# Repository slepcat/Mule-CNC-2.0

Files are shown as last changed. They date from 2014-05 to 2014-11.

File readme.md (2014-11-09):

# Mule CNC 2.0 Read me

Mule CNC 2.0は3Dプリント部品を使って構築したCNCミルです。

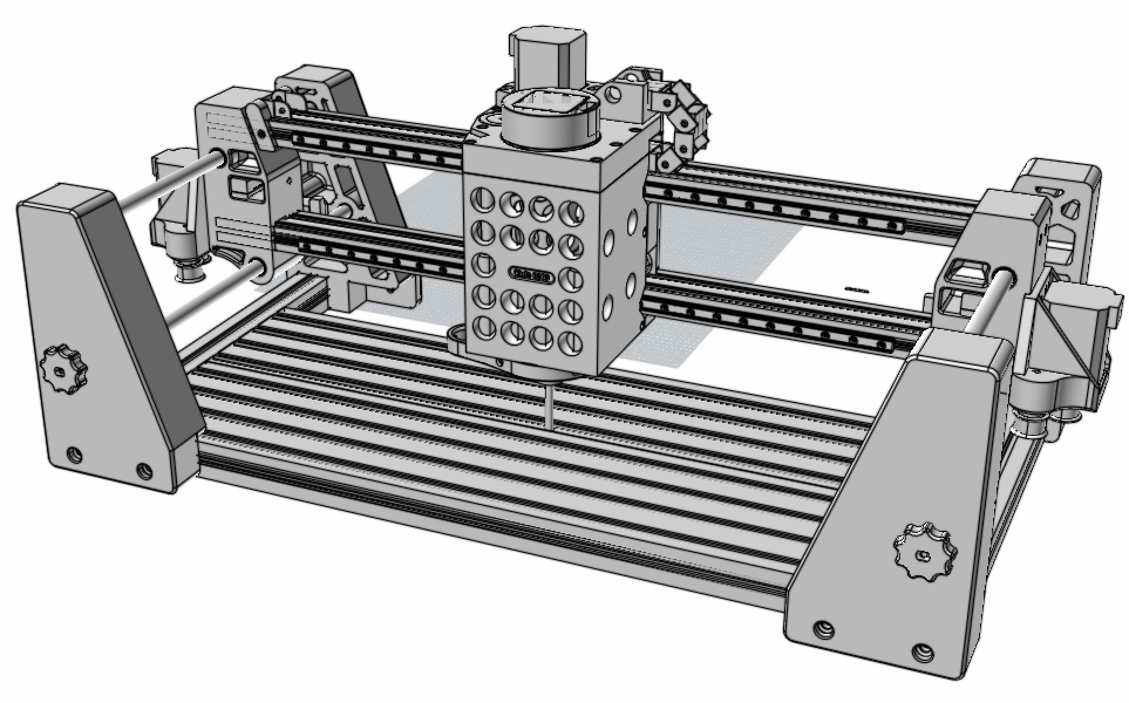
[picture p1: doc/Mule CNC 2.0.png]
Mule CNC 2.0 CAD


###主な特徴
* 3Dプリント部品。主軸を含む主要な部品をPLAで3Dプリントしています。3Dプリンタを使って構築が可能ですが、Replicator2のような造形サイズの大きいプリンタが必要です
* モーションコントローラとしてTinyGを使用しています
* 主軸モータとしてRC用のブラシレスDCモータを使用しています。	主軸回転数をTinyGから制御できます
* 剛性。アルミや真鍮といったソフトメタルを切削できます

###その他
* PLAは熱に弱いため、ステッパモータに流す電流量は注意する必要があります。発熱は3Dプリント部品を痛めるおそれがあります
* リミットスイッチはデザインに組み込まれていますが、作者はまだ実装していません
* 資料類は整理中です

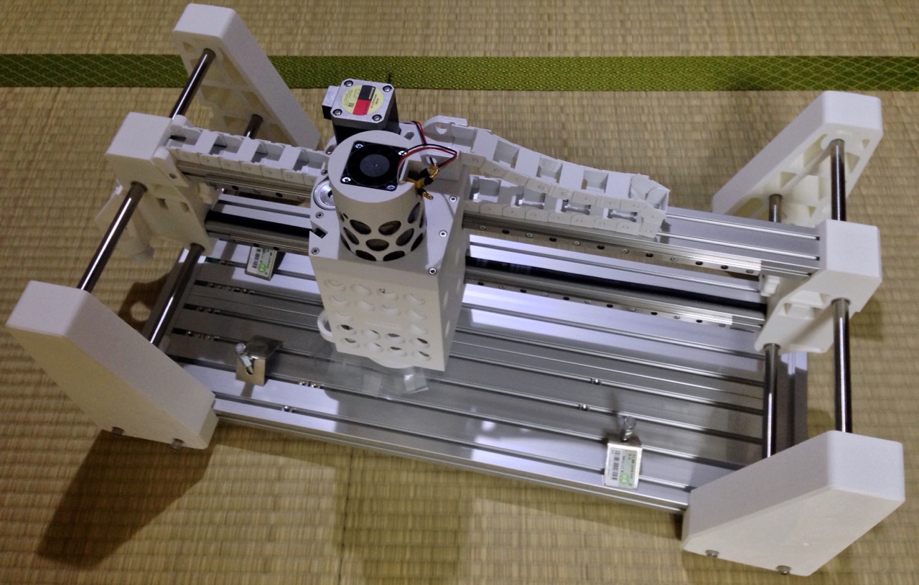
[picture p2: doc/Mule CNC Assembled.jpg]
Mule CNC under assemble


##English Ver.

Mule CNC 2.0 is CNC milling machine made with 3D Printed Parts.

###Features
* Use of 3D printed parts. Significant parts including spindle are 3D printable with PLA.
    (It require large build volume. ex, Replicator2)
* Motion controller is TinyG.
* RC's Brushless DC Motor for spindle. RPM can be controlled with TinyG.
* Rigidness. it can cut soft metals (Aluminum & Brass)
* Reduced noise.

###Note
* Mule CNC use commercial parts available in Japan. Some of them might unable to purchase outside of Japan.
* PLA is weak to heat. You should keep the current for steppers moderate to avoid heat damage.
* Limit switch has not been implemented yet.
* Documents are under construction.

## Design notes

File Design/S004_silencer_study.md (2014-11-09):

# Stepper motor silencer

マウントに防振材を挟む方式
[Motor housing with dumper](http://www.thingiverse.com/thing:25205)

モーター本体を金属たわしとアルミホイルでくるむ方式もあった筈だが論文が見つからない。
どこに行ったのか…

# Spindle silencer & EM noise sheild

アルミホイルで覆うのが手っ取り早い？

## 12th June 2014 silencer test result

* SK3 Brushless DC apx. 5000 rpm
* Use "dB-Meter Free" iPhone app. 10 cm distance from spindle.
* Results
	* 1.0 Design: avg 80dB / peak 90dB
	* Cardboard Box: avg 77dB / peak 87dB
	* Aluminum foil: avg 78dB / peak 88dB
	* Foil & steel wool: avg 76dB / peak 86dB

アルミホイルとスチールウールでも思ったほど落ちない。あとはモータをゴムでマウントする、アルミフォイルではなく厚いアルミ板を使用することを検討。

## 14th June 2014 dumper mount test result

* SK3 Brushless DC apx. 5000 rpm
* Use "dB-Meter Free" iPhone app. 10 cm distance from spindle.
* Results
	* Dumper (Rubber Mount): avg 72dB / peak 80dB
	* Dumper & foil: avg 71dB / peak 79dB

ダンパーで劇的に改善。3mm厚のゴムをThingiverseを参考に挟み込む。
Ref: [Silencer Kit for NEMA 17 Steppers](http://www.thingiverse.com/thing:25205)

Ref. Makerbot Replicator 2: avg 63dB / peak 73dB

## 16th June 2013 lead tape test result

* SK3 Brushless DC apx. 5000 rpm
* Use "dB-Meter Free" iPhone app. 10 cm distance from spindle.
* dc housing with silencer case
* Results
	* Dumper, on the towel: avg 69dB / peak 76dB
	* Dumper: avg 72dB / peak 80dB
	* Dumper, lead tape, on the sponge avg 69dB / peak 76dB

鉛テープに効果なし。ハウジングとスピンドルブロックにダンパーを挟み込むことに効果がありそう
だと判明。

音響インピーダンスに付いてアドバイスをもらう。空気／スポンジ／鉛テープの層にすれば効果があ
るかも。

## 17th June 2014 sponge test result

* SK3 Brushless DC apx. 5000 rpm
* Use "dB-Meter Free" iPhone app. 10 cm distance from spindle.
* dc housing with silencer case
* Results
	* Dumper, lead/sponge on sponge: avg 65dB / peak 72dB

効果があるようですが放熱が心配。

ノイズ対策レシピ
Anti Noise recipes from CNC Cookbook
http://www.cnccookbook.com/CCCNCNoise.html

## 14th September 2014 new motor

* SNTM 28-26 1100KV Brushless DC apx. 5000 rpm?
* Use "dB-Meter Free" iPhone app. 10 cm distance from spindle.
* dc housing with silencer case
* Results
	* Dumper: avg 60dB / peak 67dB

モータ交換した事で劇的に改善。しばらくSK3で運用していたがこちらに交換する事を決断。ハウジングのデザインも多少見直す予定。
なお、SK3はシャフトに取り付けていた軸ががたついていたのでこれも騒音の一因だったかも。いずれにしても高回転のモータは騒音面でデメリットが大きいかも。SK3しか使っていないので分かりませんが。

## 9th November 2014 Round up

本体に組み込んだところ、ハウジングの振動でキャリッジと接触して騒音が大きくなることが判明。
スピンドル周りを一回り小さくなるように造形し直し、キャリッジとクリアランスを確保。
スピンドルを再作成する際に排気口を追加、スピンドルモータの冷却風がスピンドル下面から流れ出るようにデザインを修正。これでハウジングに排気口をつける必要がなくなり騒音を密閉できるように。また切削時のエアブローとしても多少期待できるかも？

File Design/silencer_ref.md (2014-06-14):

# Stepper motor silencer

マウントに防振材を挟む方式
[Motor housing with dumper](http://www.thingiverse.com/thing:25205)

モーター本体を金属たわしとアルミホイルでくるむ方式もあった筈だが論文が見つからない。
どこに行ったのか…
I've seen the paper describe stepper silencer with aluminium foil and steel wool, but I cann't find it.

# Spindle silencer & EM noise sheild

アルミホイルで覆うのが手っ取り早い？
Aluminum sheet may be good considering EM noise of Spindle...

## 12th June 2014 silencer test result

* SK3 Brushless DC apx. 5000rpm
* Use "dB-Meter Free" iPhone app. 10cm distance from spindle.
* Resutls
	* 1.0 Design: avg 80dB / peak 90db
	* Cardboard Box: avg 77dB / peak 87dB
	* Aluminum foil: avg 78dB / peak 88dB
	* Foil & steel wool: avg 76dB / peak 86dB

アルミホイルとスチールウールでも思ったほど落ちない。あとはモータをゴムでマウントする、アルミフォイルではなく厚いアルミ板を使用することを検討。
Foil & steel wool failed to reach the expectation. Motor housing with dumper and thicker aluminum sheet may be effective.

## 14th June 2014 dumper mount test result

* SK3 Brushless DC apx. 5000rpm
* Use "dB-Meter Free" iPhone app. 10cm distance from spindle.
* Resutls
	* Dumper (Rubber Mount): avg 72dB / peak 80dB
	* Sumper & foil: avg 71dB / peak 79dB

Use dumper mount of 3mm thickness rubber sheets. Big improvement!
ダンパーで劇的に改善。3mm厚のゴムをThingiverseを参考に挟み込む。
Ref: [Silencer Kit for NEMA 17 Steppers](http://www.thingiverse.com/thing:25205)

ノイズ対策レシピ
Anti Noise recipes from CNC Cookbook
http://www.cnccookbook.com/CCCNCNoise.html

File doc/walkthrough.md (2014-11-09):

#フォルダ構成の説明

* CAD/ : MoI 2.5で作成したCADデータ。市販部品のデータが組み込まれていますが、こちらは当然元々のメーカのものですのでご注意ください
* Design/ : 静音化のときの試行錯誤のメモとか、強度計算もどきのメモなんかが残っています
* doc/ : ライセンスとこのファイル。BoMもここに入れる予定です
* readme.md
* STL & NC : CADデータから出力したstlデータです。3Dプリント用にサポートなどがついた状態になっています
* Test : 製作時に行った各種テストのデータです
	* Arduino_rpm_sensor : Arduinoを使った主軸回転数計。要改良
	* Arduino_tmp_sensor : Arduinoを使った温度計

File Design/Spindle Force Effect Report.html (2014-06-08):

(https://forceeffect.autodesk.com)

For correct interpretation of this picture you need to use IE9, Chrome, Safari or Firefox

## Inputs:

### Elements

Element | Length | Weight
A-B | 49.000 mm
B-C | 91.000 mm
B-D | 42.000 mm
A-E | 42.000 mm

### Forces

Force | Direction | Size | Angle
F1 | | 50.000 N | 360.0°
F2 | | 10.000 N | 90.2°

## Results:

Overconstrained System: No equations available.

### Reaction Forces

Force | Direction | Size | Angle
RD | | 138.563 N | 206.5°
RE | | 90.375 N | 35.0°

### Reaction Moments

Moment | Direction | Size
MD | | 546.977 Nmm
ME | | 1043.665 Nmm

## Element A-B

For correct interpretation of this picture you need to use IE9, Chrome, Safari or Firefox

Results (No equations available)
Mr3s1i11 = −1132.734 Nmm Mr3s1i2 = 1132.734 Nmm Mr3s2i5 = −4546.652 Nmm Mr3s2i8 = 2049.606 Nmm Mr6s1i2 = 2497.046 Nmm | Rr1s1i11 = −74.048 N Rr1s1i2 = 74.048 N Rr1s2i5 = −49.964 N Rr1s2i8 = 124.012 N Rr2s1i11 = −51.812 N | Rr2s1i2 = 51.812 N Rr2s2i5 = −10.000 N Rr2s2i8 = 61.812 N Rr4s1i2 = −74.048 N Rr5s1i2 = −51.812 N

### Shear Force and Moment Diagram

For correct interpretation of this picture you need to use IE9, Chrome, Safari or Firefox

For correct interpretation of this picture you need to use IE9, Chrome, Safari or Firefox

For correct interpretation of this picture you need to use IE9, Chrome, Safari or Firefox

## Element A-E

For correct interpretation of this picture you need to use IE9, Chrome, Safari or Firefox

Results (No equations available)
Mr3s1i11 = −1132.734 Nmm Mr3s1i2 = 1132.734 Nmm Mr6s1i11 = −1043.665 Nmm | Rr1s1i11 = −74.048 N Rr1s1i2 = 74.048 N Rr2s1i11 = −51.812 N | Rr2s1i2 = 51.812 N Rr4s1i11 = 74.048 N Rr5s1i11 = 51.812 N

### Shear Force and Moment Diagram

For correct interpretation of this picture you need to use IE9, Chrome, Safari or Firefox

For correct interpretation of this picture you need to use IE9, Chrome, Safari or Firefox

## Element B-C

For correct interpretation of this picture you need to use IE9, Chrome, Safari or Firefox

Results (No equations available)
Mr3s2i5 = −4546.652 Nmm Mr3s2i8 = 2049.606 Nmm Mr6s1i2 = 2497.046 Nmm Mr6s2i5 = 0.000 Nmm | Rr1s2i5 = −49.964 N Rr1s2i8 = 124.012 N Rr2s2i5 = −10.000 N Rr2s2i8 = 61.812 N | Rr4s1i2 = −74.048 N Rr4s2i5 = 49.964 N Rr5s1i2 = −51.812 N Rr5s2i5 = 10.000 N

### Shear Force and Moment Diagram

For correct interpretation of this picture you need to use IE9, Chrome, Safari or Firefox

For correct interpretation of this picture you need to use IE9, Chrome, Safari or Firefox

For correct interpretation of this picture you need to use IE9, Chrome, Safari or Firefox

## Element B-D

For correct interpretation of this picture you need to use IE9, Chrome, Safari or Firefox

Results (No equations available)
Mr3s2i5 = −4546.652 Nmm Mr3s2i8 = 2049.606 Nmm Mr6s1i2 = 2497.046 Nmm Mr6s2i8 = 546.977 Nmm | Rr1s2i5 = −49.964 N Rr1s2i8 = 124.012 N Rr2s2i5 = −10.000 N Rr2s2i8 = 61.812 N | Rr4s1i2 = −74.048 N Rr4s2i8 = −124.012 N Rr5s1i2 = −51.812 N Rr5s2i8 = −61.812 N

### Shear Force and Moment Diagram

For correct interpretation of this picture you need to use IE9, Chrome, Safari or Firefox

For correct interpretation of this picture you need to use IE9, Chrome, Safari or Firefox

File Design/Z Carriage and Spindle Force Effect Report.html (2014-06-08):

(https://forceeffect.autodesk.com)

For correct interpretation of this picture you need to use IE9, Chrome, Safari or Firefox

## Inputs:

### Elements

Element | Length | Weight
A-B | 49.000 mm
B-C | 91.000 mm
B-D | 42.000 mm
A-E | 42.000 mm
D-F | 10.000 mm
D-E | 49.000 mm
E-G | 81.000 mm

### Forces

Force | Direction | Size | Angle
F1 | | 50.000 N | 360.0°
F2 | | 10.000 N | 90.2°

## Results:

Overconstrained System: No equations available.

### Reaction Forces

Force | Direction | Size | Angle
RF | | 100.105 N | 214.0°
RG | | 56.623 N | 54.3°

### Reaction Moments

Moment | Direction | Size
MF | | 160.443 Nmm
MG | | 1155.783 Nmm

## Element A-B

For correct interpretation of this picture you need to use IE9, Chrome, Safari or Firefox

Results (No equations available)
Mr3s1i11 = −928.458 Nmm Mr3s1i2 = 928.458 Nmm Mr3s2i5 = −4546.652 Nmm Mr3s2i8 = 2126.766 Nmm Mr6s1i2 = 2419.887 Nmm | Rr1s1i11 = −68.310 N Rr1s1i2 = 68.310 N Rr1s2i5 = −49.964 N Rr1s2i8 = 118.274 N Rr2s1i11 = −41.972 N | Rr2s1i2 = 41.972 N Rr2s2i5 = −10.000 N Rr2s2i8 = 51.972 N Rr4s1i2 = −68.310 N Rr5s1i2 = −41.972 N

### Shear Force and Moment Diagram

For correct interpretation of this picture you need to use IE9, Chrome, Safari or Firefox

For correct interpretation of this picture you need to use IE9, Chrome, Safari or Firefox

For correct interpretation of this picture you need to use IE9, Chrome, Safari or Firefox

## Element A-E

For correct interpretation of this picture you need to use IE9, Chrome, Safari or Firefox

Results (No equations available)
Mr3s11i23 = 1517.740 Nmm Mr3s1i11 = −928.458 Nmm Mr3s1i2 = 928.458 Nmm Mr6s1i11 = −834.618 Nmm Mr6s8i11 = −683.122 Nmm | Rr1s11i23 = −33.006 N Rr1s1i11 = −68.310 N Rr1s1i2 = 68.310 N Rr2s11i23 = −46.008 N Rr2s1i11 = −41.972 N | Rr2s1i2 = 41.972 N Rr4s1i11 = 68.310 N Rr4s8i11 = −35.304 N Rr5s1i11 = 41.972 N Rr5s8i11 = 4.036 N

### Shear Force and Moment Diagram

For correct interpretation of this picture you need to use IE9, Chrome, Safari or Firefox

For correct interpretation of this picture you need to use IE9, Chrome, Safari or Firefox

## Element B-C

For correct interpretation of this picture you need to use IE9, Chrome, Safari or Firefox

Results (No equations available)
Mr3s2i5 = −4546.652 Nmm Mr3s2i8 = 2126.766 Nmm Mr6s1i2 = 2419.887 Nmm Mr6s2i5 = 0.000 Nmm | Rr1s2i5 = −49.964 N Rr1s2i8 = 118.274 N Rr2s2i5 = −10.000 N Rr2s2i8 = 51.972 N | Rr4s1i2 = −68.310 N Rr4s2i5 = 49.964 N Rr5s1i2 = −41.972 N Rr5s2i5 = 10.000 N

### Shear Force and Moment Diagram

For correct interpretation of this picture you need to use IE9, Chrome, Safari or Firefox

For correct interpretation of this picture you need to use IE9, Chrome, Safari or Firefox

For correct interpretation of this picture you need to use IE9, Chrome, Safari or Firefox

## Element B-D

For correct interpretation of this picture you need to use IE9, Chrome, Safari or Firefox

Results (No equations available)
Mr3s2i5 = −4546.652 Nmm Mr3s2i8 = 2126.766 Nmm Mr3s8i11 = −1046.645 Nmm Mr3s8i19 = 990.149 Nmm Mr6s1i2 = 2419.887 Nmm Mr6s2i8 = 56.496 Nmm | Rr1s2i5 = −49.964 N Rr1s2i8 = 118.274 N Rr1s8i11 = 35.304 N Rr1s8i19 = 82.971 N Rr2s2i5 = −10.000 N Rr2s2i8 = 51.972 N | Rr2s8i11 = −4.036 N Rr2s8i19 = 56.007 N Rr4s1i2 = −68.310 N Rr4s2i8 = −118.274 N Rr5s1i2 = −41.972 N Rr5s2i8 = −51.972 N

### Shear Force and Moment Diagram

For correct interpretation of this picture you need to use IE9, Chrome, Safari or Firefox

For correct interpretation of this picture you need to use IE9, Chrome, Safari or Firefox

## Element D-E

For correct interpretation of this picture you need to use IE9, Chrome, Safari or Firefox

Results (No equations available)
Mr3s11i23 = 1517.740 Nmm Mr3s8i11 = −1046.645 Nmm Mr3s8i19 = 990.149 Nmm Mr6s1i11 = −834.618 Nmm Mr6s2i8 = 56.496 Nmm Mr6s8i11 = −683.122 Nmm | Rr1s11i23 = −33.006 N Rr1s8i11 = 35.304 N Rr1s8i19 = 82.971 N Rr2s11i23 = −46.008 N Rr2s8i11 = −4.036 N Rr2s8i19 = 56.007 N | Rr4s1i11 = 68.310 N Rr4s2i8 = −118.274 N Rr4s8i11 = −35.304 N Rr5s1i11 = 41.972 N Rr5s2i8 = −51.972 N Rr5s8i11 = 4.036 N

### Shear Force and Moment Diagram

For correct interpretation of this picture you need to use IE9, Chrome, Safari or Firefox

For correct interpretation of this picture you need to use IE9, Chrome, Safari or Firefox

For correct interpretation of this picture you need to use IE9, Chrome, Safari or Firefox

## Element D-F

For correct interpretation of this picture you need to use IE9, Chrome, Safari or Firefox

Results (No equations available)
Mr3s8i11 = −1046.645 Nmm Mr3s8i19 = 990.149 Nmm Mr6s2i8 = 56.496 Nmm Mr6s8i19 = −160.443 Nmm | Rr1s8i11 = 35.304 N Rr1s8i19 = 82.971 N Rr2s8i11 = −4.036 N Rr2s8i19 = 56.007 N | Rr4s2i8 = −118.274 N Rr4s8i19 = −82.971 N Rr5s2i8 = −51.972 N Rr5s8i19 = −56.007 N

### Shear Force and Moment Diagram

For correct interpretation of this picture you need to use IE9, Chrome, Safari or Firefox

For correct interpretation of this picture you need to use IE9, Chrome, Safari or Firefox

## Element E-G

For correct interpretation of this picture you need to use IE9, Chrome, Safari or Firefox

Results (No equations available)
Mr3s11i23 = 1517.740 Nmm Mr6s11i23 = 1155.783 Nmm Mr6s1i11 = −834.618 Nmm Mr6s8i11 = −683.122 Nmm | Rr1s11i23 = −33.006 N Rr2s11i23 = −46.008 N Rr4s11i23 = 33.006 N Rr4s1i11 = 68.310 N | Rr4s8i11 = −35.304 N Rr5s11i23 = 46.008 N Rr5s1i11 = 41.972 N Rr5s8i11 = 4.036 N

### Shear Force and Moment Diagram

For correct interpretation of this picture you need to use IE9, Chrome, Safari or Firefox

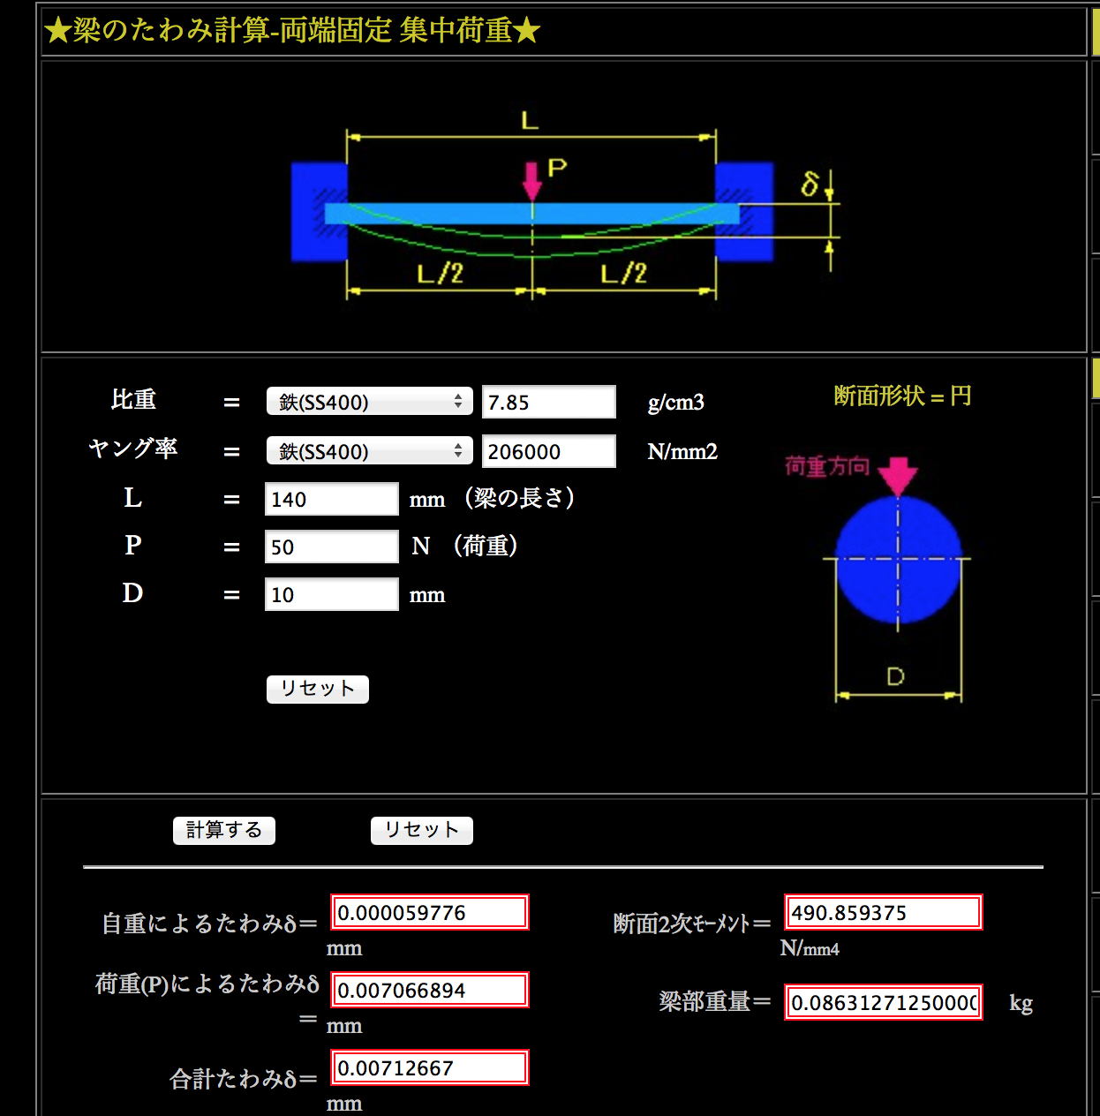
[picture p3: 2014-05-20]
Design/Z Axis Shaft Strength Calc.png

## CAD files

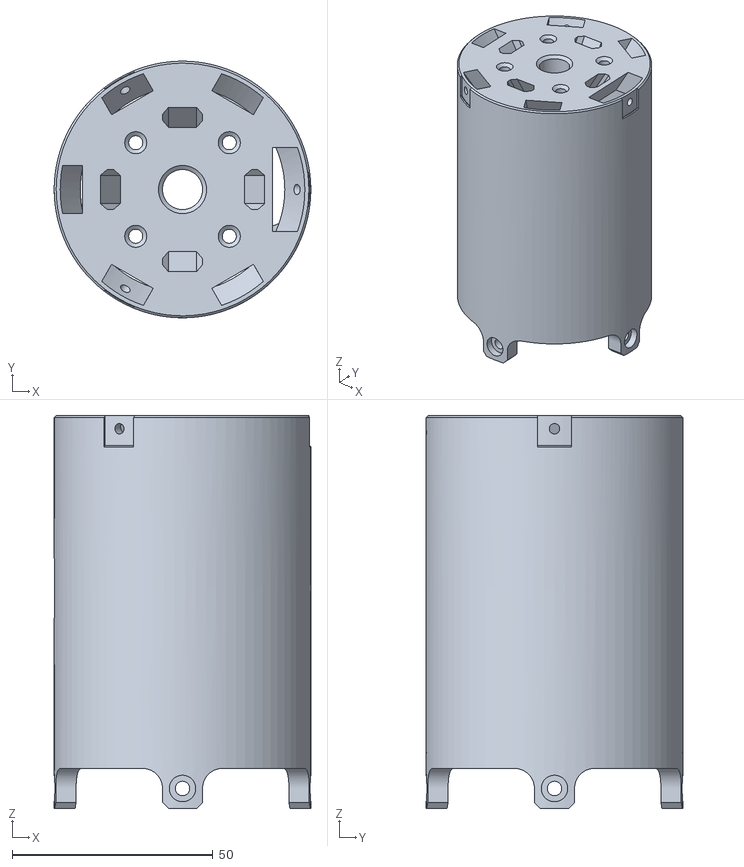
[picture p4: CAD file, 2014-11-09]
STL&NC/S001 dc housing 2.2.stl
64.0 x 64.0 x 98.0

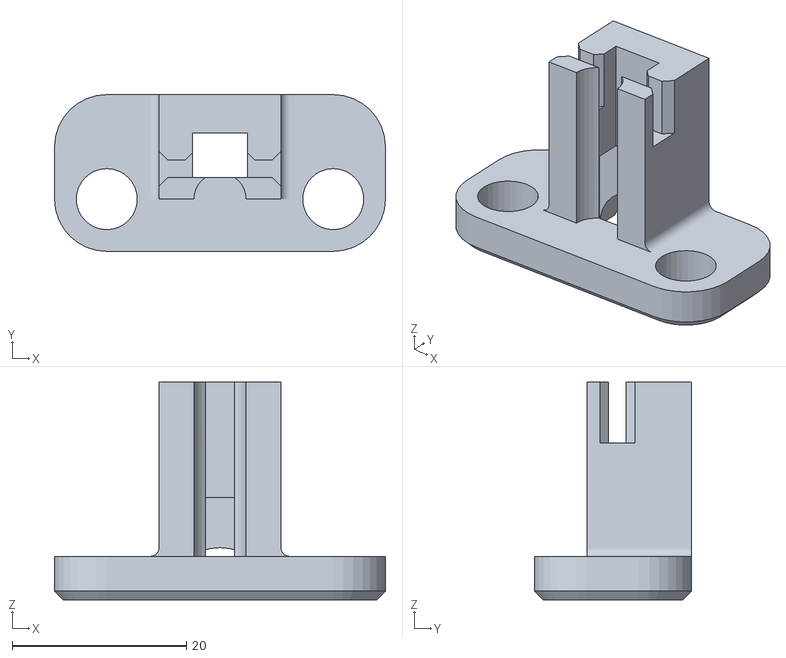
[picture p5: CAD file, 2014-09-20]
Test/SensorMount.stl
38.0 x 18.0 x 25.0

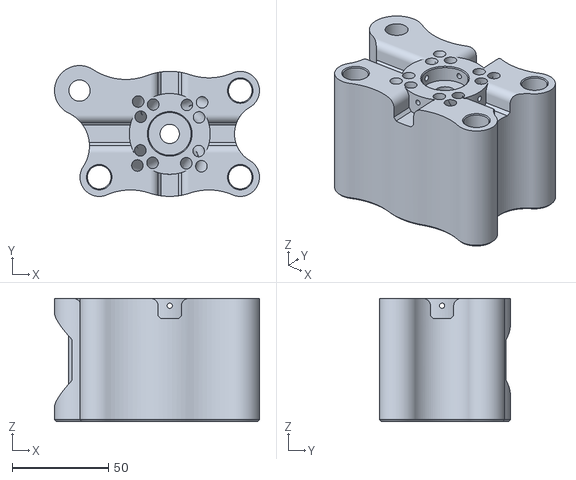
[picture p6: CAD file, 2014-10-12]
STL&NC/S002 spindle 2.2.stl
106.5 x 68.0 x 64.0

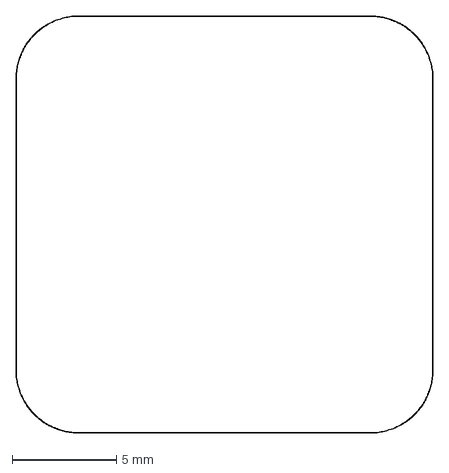
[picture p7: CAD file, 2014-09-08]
Test/tab.dxf
20.0 x 20.0 mm

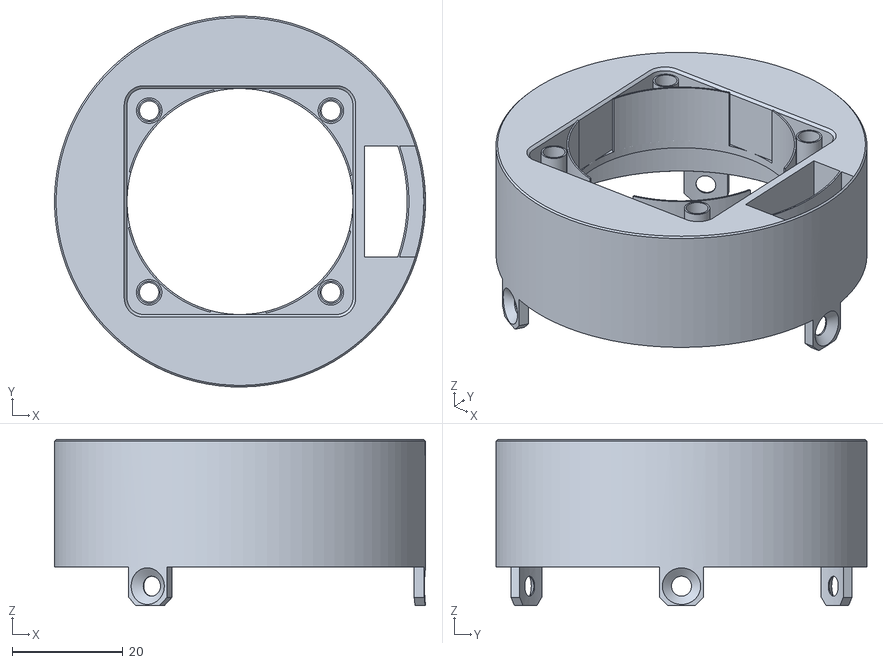
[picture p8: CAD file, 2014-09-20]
STL&NC/S005 silencer cover 2.2.stl
67.0 x 67.0 x 30.0

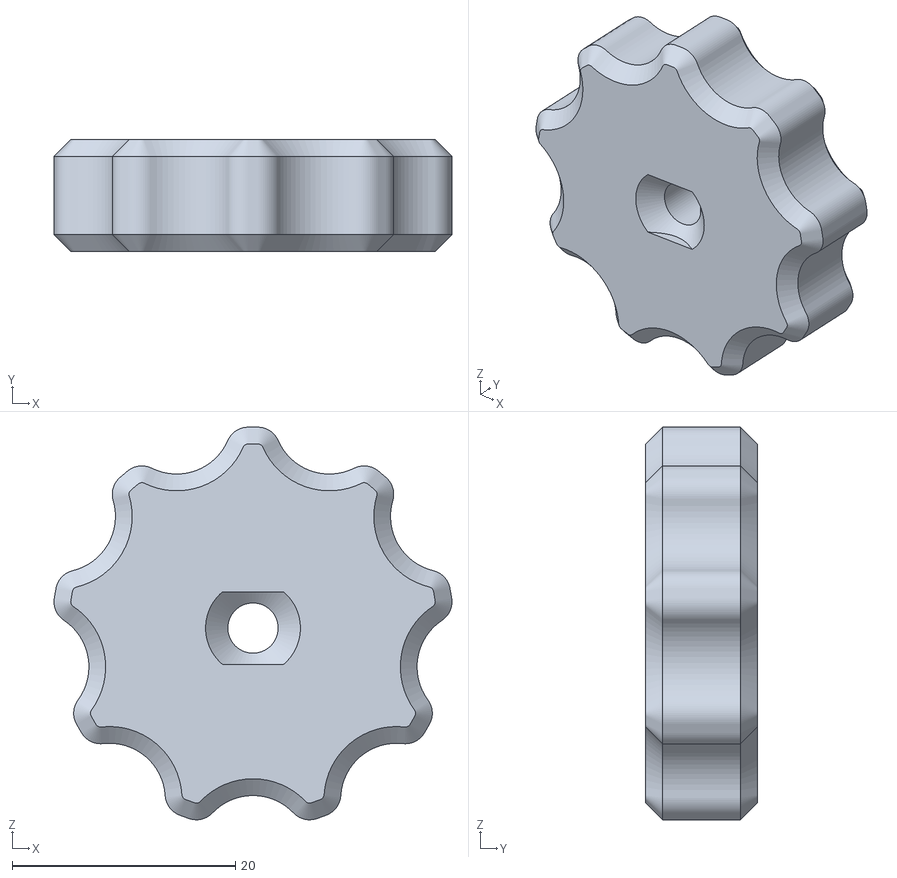
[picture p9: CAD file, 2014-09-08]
STL&NC/Y003-3 adjuster handle.stl
35.6 x 10.0 x 35.2

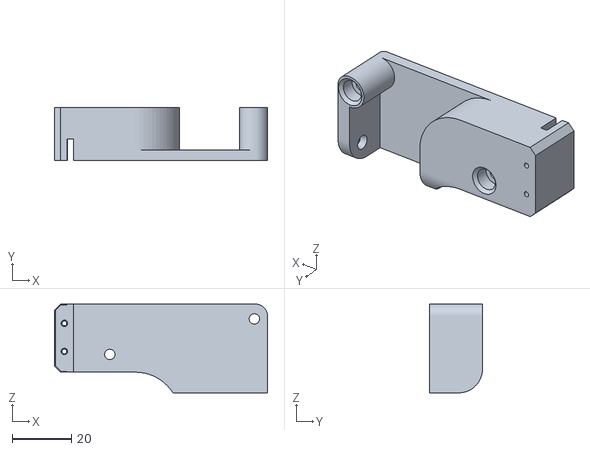
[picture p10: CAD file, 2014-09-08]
STL&NC/accesory bracket right.stl
72.0 x 17.9 x 30.0

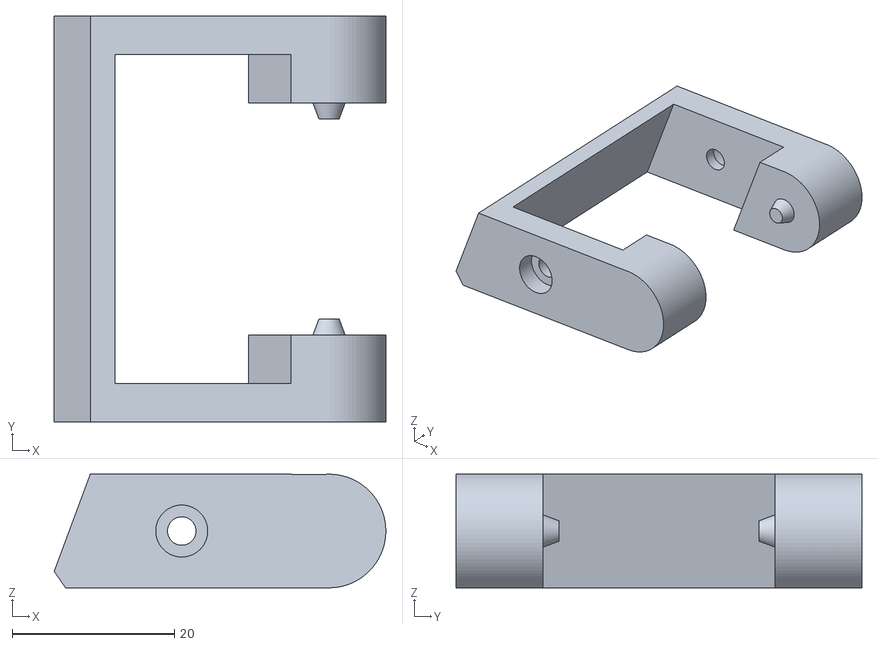
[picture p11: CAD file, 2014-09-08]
STL&NC/X007 cable terminal.stl
40.8 x 50.0 x 14.0

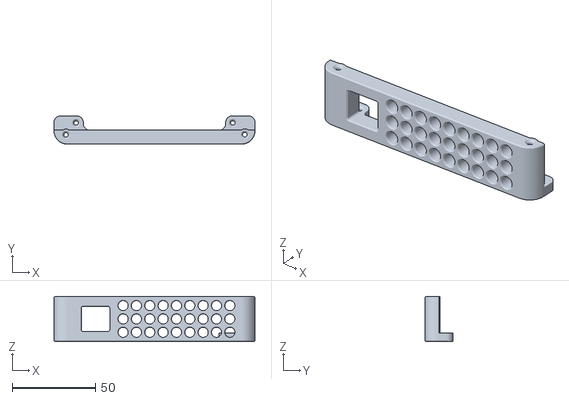
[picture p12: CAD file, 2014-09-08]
STL&NC/tinyg case usb.stl
120.5 x 17.0 x 27.0

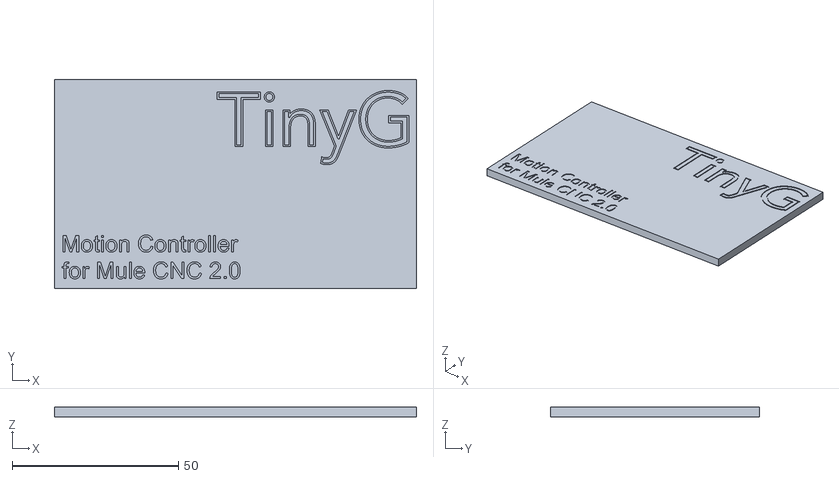
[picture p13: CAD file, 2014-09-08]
STL&NC/engrave.stl
109.0 x 63.0 x 3.00

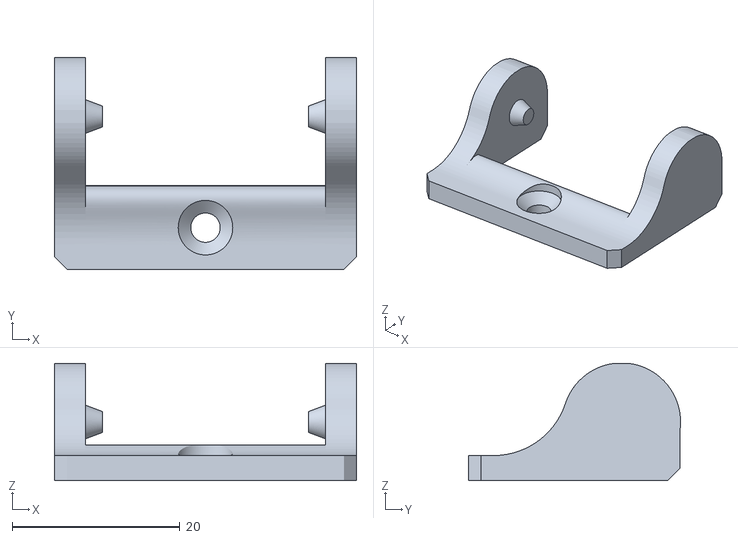
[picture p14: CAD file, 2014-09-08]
STL&NC/Y007 cable terminal.stl
36.0 x 25.3 x 14.0

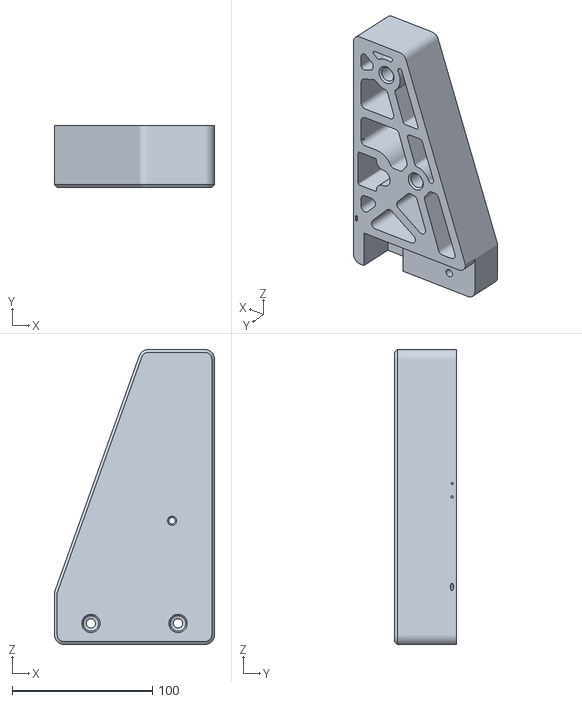
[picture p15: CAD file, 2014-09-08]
STL&NC/Y001 y frame front right.stl
114.0 x 44.0 x 210.0

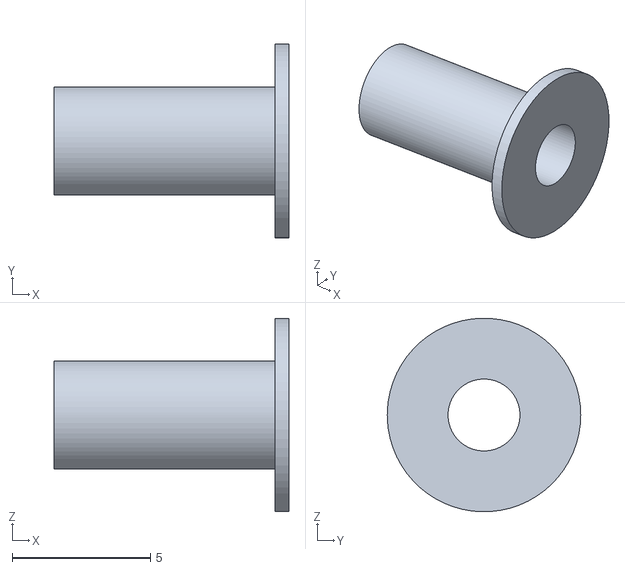
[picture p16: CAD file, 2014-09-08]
STL&NC/helisert.stl
8.50 x 7.00 x 7.00

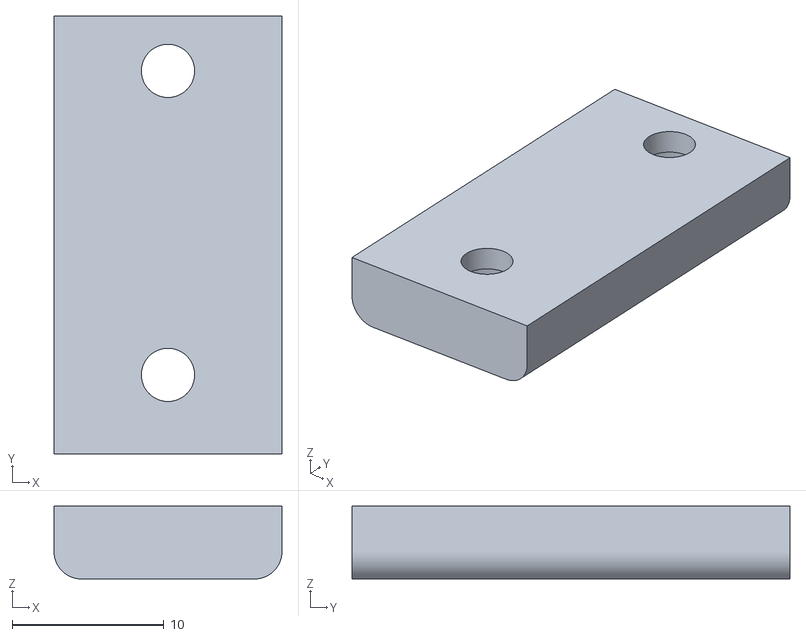
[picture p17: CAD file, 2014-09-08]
STL&NC/X005-4 belt lock.stl
15.0 x 28.8 x 4.80

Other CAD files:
STL&NC/Y004 rear frame left.stl
STL&NC/X005-2 adjuster handle.stl
STL&NC/Y01-2 belt lock.stl
STL&NC/U001-3 spacer.stl
CAD/Cable Carriror.3dm
CAD/X Motor Housing.3dm
CAD/X003 right bracket.3dm
CAD/X005 left bracket.3dm
CAD/Y001-1 belt lock.3dm
CAD/Z Carriage Cover.3dm
CAD/Z Carriage.3dm
CAD/Z Motor Mount.3dm
STL&NC/S001 dc housing.stl
STL&NC/U001 smooth idler.stl
STL&NC/U001-2 spacer.stl
STL&NC/X001 motor housing.stl
STL&NC/X003 right bracket.stl
STL&NC/X005 left bracket.stl
STL&NC/X005-3 belt lock.stl
STL&NC/X007 right bracket.stl
STL&NC/Y001 y motor mount.stl
STL&NC/Y001-1 belt lock.stl
STL&NC/Y002 front frame left.stl
STL&NC/Y003 rear frame right.stl
STL&NC/Z001 z carriage.stl
STL&NC/Z001-3 spacer.stl
STL&NC/Z001-4 coller.stl
STL&NC/Z003 cover.stl
STL&NC/Z005 z motor housing.stl
STL&NC/Z006 dust skirt.stl
STL&NC/accesory bracket left.stl
STL&NC/plate.stl
STL&NC/tinyg case power.stl

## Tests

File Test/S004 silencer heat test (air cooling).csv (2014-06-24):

Temp(Celsius): 25 | Time(Second): 0
Temp(Celsius): 25 | Time(Second): 1
Temp(Celsius): 25 | Time(Second): 2
Temp(Celsius): 25 | Time(Second): 3
Temp(Celsius): 25 | Time(Second): 4
Temp(Celsius): 25 | Time(Second): 5
Temp(Celsius): 25 | Time(Second): 6
Temp(Celsius): 25 | Time(Second): 7
Temp(Celsius): 25 | Time(Second): 8
Temp(Celsius): 25 | Time(Second): 9
Temp(Celsius): 25 | Time(Second): 10
Temp(Celsius): 25 | Time(Second): 11
Temp(Celsius): 25 | Time(Second): 12
Temp(Celsius): 25 | Time(Second): 13
Temp(Celsius): 25 | Time(Second): 14
Temp(Celsius): 25 | Time(Second): 15
Temp(Celsius): 25 | Time(Second): 16
Temp(Celsius): 25 | Time(Second): 17
Temp(Celsius): 25 | Time(Second): 18
Temp(Celsius): 25 | Time(Second): 19
Temp(Celsius): 25 | Time(Second): 20
Temp(Celsius): 25 | Time(Second): 21
Temp(Celsius): 25 | Time(Second): 22
Temp(Celsius): 25 | Time(Second): 23
Temp(Celsius): 25 | Time(Second): 24
Temp(Celsius): 25 | Time(Second): 25
Temp(Celsius): 25 | Time(Second): 26
Temp(Celsius): 25 | Time(Second): 27
Temp(Celsius): 25 | Time(Second): 28
Temp(Celsius): 25 | Time(Second): 29
Temp(Celsius): 25 | Time(Second): 30
Temp(Celsius): 25 | Time(Second): 31
Temp(Celsius): 25 | Time(Second): 32
Temp(Celsius): 25 | Time(Second): 33
Temp(Celsius): 25 | Time(Second): 34
Temp(Celsius): 25 | Time(Second): 35
Temp(Celsius): 25 | Time(Second): 36
Temp(Celsius): 25 | Time(Second): 37
Temp(Celsius): 25 | Time(Second): 38
Temp(Celsius): 25 | Time(Second): 39
Temp(Celsius): 25 | Time(Second): 40
Temp(Celsius): 25 | Time(Second): 41
Temp(Celsius): 25 | Time(Second): 42
Temp(Celsius): 25 | Time(Second): 43
Temp(Celsius): 25 | Time(Second): 44
Temp(Celsius): 25 | Time(Second): 45
Temp(Celsius): 26 | Time(Second): 46
Temp(Celsius): 25 | Time(Second): 47
Temp(Celsius): 25 | Time(Second): 48
Temp(Celsius): 25 | Time(Second): 49
Temp(Celsius): 25 | Time(Second): 50
Temp(Celsius): 25 | Time(Second): 51
Temp(Celsius): 25 | Time(Second): 52
Temp(Celsius): 26 | Time(Second): 53
Temp(Celsius): 25 | Time(Second): 54
Temp(Celsius): 25 | Time(Second): 55
Temp(Celsius): 25 | Time(Second): 56
Temp(Celsius): 25 | Time(Second): 57
Temp(Celsius): 25 | Time(Second): 58
Temp(Celsius): 25 | Time(Second): 59
Temp(Celsius): 25 | Time(Second): 60
Temp(Celsius): 25 | Time(Second): 61
Temp(Celsius): 25 | Time(Second): 62
Temp(Celsius): 25 | Time(Second): 63
Temp(Celsius): 26 | Time(Second): 64
Temp(Celsius): 25 | Time(Second): 65
Temp(Celsius): 25 | Time(Second): 66
Temp(Celsius): 25 | Time(Second): 67
Temp(Celsius): 26 | Time(Second): 68
Temp(Celsius): 26 | Time(Second): 69
Temp(Celsius): 25 | Time(Second): 70
Temp(Celsius): 26 | Time(Second): 71
Temp(Celsius): 26 | Time(Second): 72
Temp(Celsius): 26 | Time(Second): 73
Temp(Celsius): 26 | Time(Second): 74
Temp(Celsius): 26 | Time(Second): 75
Temp(Celsius): 26 | Time(Second): 76
Temp(Celsius): 26 | Time(Second): 77
Temp(Celsius): 26 | Time(Second): 78
Temp(Celsius): 26 | Time(Second): 79
Temp(Celsius): 26 | Time(Second): 80
Temp(Celsius): 26 | Time(Second): 81
Temp(Celsius): 26 | Time(Second): 82
Temp(Celsius): 26 | Time(Second): 83
Temp(Celsius): 26 | Time(Second): 84
Temp(Celsius): 26 | Time(Second): 85
Temp(Celsius): 26 | Time(Second): 86
Temp(Celsius): 25 | Time(Second): 87
Temp(Celsius): 26 | Time(Second): 88
Temp(Celsius): 26 | Time(Second): 89
Temp(Celsius): 26 | Time(Second): 90
Temp(Celsius): 26 | Time(Second): 91
Temp(Celsius): 26 | Time(Second): 92
Temp(Celsius): 26 | Time(Second): 93
Temp(Celsius): 26 | Time(Second): 94
Temp(Celsius): 26 | Time(Second): 95
Temp(Celsius): 26 | Time(Second): 96
Temp(Celsius): 26 | Time(Second): 97
Temp(Celsius): 26 | Time(Second): 98
Temp(Celsius): 26 | Time(Second): 99
Temp(Celsius): 26 | Time(Second): 100
Temp(Celsius): 26 | Time(Second): 101
Temp(Celsius): 26 | Time(Second): 102
Temp(Celsius): 26 | Time(Second): 103
Temp(Celsius): 26 | Time(Second): 104
Temp(Celsius): 26 | Time(Second): 105
Temp(Celsius): 26 | Time(Second): 106
Temp(Celsius): 26 | Time(Second): 107
Temp(Celsius): 26 | Time(Second): 108
Temp(Celsius): 26 | Time(Second): 109
Temp(Celsius): 26 | Time(Second): 110
Temp(Celsius): 26 | Time(Second): 111
Temp(Celsius): 26 | Time(Second): 112
Temp(Celsius): 26 | Time(Second): 113
Temp(Celsius): 26 | Time(Second): 114
Temp(Celsius): 26 | Time(Second): 115
Temp(Celsius): 26 | Time(Second): 116
Temp(Celsius): 26 | Time(Second): 117
Temp(Celsius): 26 | Time(Second): 118
Temp(Celsius): 26 | Time(Second): 119
Temp(Celsius): 26 | Time(Second): 120
Temp(Celsius): 27 | Time(Second): 121
Temp(Celsius): 27 | Time(Second): 122
Temp(Celsius): 27 | Time(Second): 123
Temp(Celsius): 27 | Time(Second): 124
Temp(Celsius): 27 | Time(Second): 125
Temp(Celsius): 27 | Time(Second): 126
Temp(Celsius): 27 | Time(Second): 127
Temp(Celsius): 27 | Time(Second): 128
Temp(Celsius): 27 | Time(Second): 129
Temp(Celsius): 27 | Time(Second): 130
Temp(Celsius): 27 | Time(Second): 131
Temp(Celsius): 27 | Time(Second): 132
Temp(Celsius): 27 | Time(Second): 133
Temp(Celsius): 27 | Time(Second): 134
Temp(Celsius): 27 | Time(Second): 135
Temp(Celsius): 27 | Time(Second): 136
Temp(Celsius): 27 | Time(Second): 137
Temp(Celsius): 27 | Time(Second): 138
Temp(Celsius): 27 | Time(Second): 139
Temp(Celsius): 27 | Time(Second): 140
Temp(Celsius): 27 | Time(Second): 141
Temp(Celsius): 27 | Time(Second): 142
Temp(Celsius): 27 | Time(Second): 143
Temp(Celsius): 27 | Time(Second): 144
Temp(Celsius): 27 | Time(Second): 145
Temp(Celsius): 28 | Time(Second): 146
Temp(Celsius): 27 | Time(Second): 147
Temp(Celsius): 28 | Time(Second): 148
Temp(Celsius): 28 | Time(Second): 149
Temp(Celsius): 28 | Time(Second): 150
Temp(Celsius): 28 | Time(Second): 151
Temp(Celsius): 28 | Time(Second): 152
Temp(Celsius): 28 | Time(Second): 153
Temp(Celsius): 28 | Time(Second): 154
Temp(Celsius): 28 | Time(Second): 155
Temp(Celsius): 28 | Time(Second): 156
Temp(Celsius): 28 | Time(Second): 157
Temp(Celsius): 28 | Time(Second): 158
Temp(Celsius): 28 | Time(Second): 159
Temp(Celsius): 28 | Time(Second): 160
Temp(Celsius): 28 | Time(Second): 161
Temp(Celsius): 28 | Time(Second): 162
Temp(Celsius): 28 | Time(Second): 163
Temp(Celsius): 28 | Time(Second): 164
Temp(Celsius): 29 | Time(Second): 165
Temp(Celsius): 28 | Time(Second): 166
Temp(Celsius): 28 | Time(Second): 167
Temp(Celsius): 28 | Time(Second): 168
Temp(Celsius): 28 | Time(Second): 169
Temp(Celsius): 29 | Time(Second): 170
Temp(Celsius): 28 | Time(Second): 171
Temp(Celsius): 28 | Time(Second): 172
Temp(Celsius): 29 | Time(Second): 173
Temp(Celsius): 29 | Time(Second): 174
Temp(Celsius): 29 | Time(Second): 175
Temp(Celsius): 29 | Time(Second): 176
Temp(Celsius): 29 | Time(Second): 177
Temp(Celsius): 29 | Time(Second): 178
Temp(Celsius): 29 | Time(Second): 179
Temp(Celsius): 29 | Time(Second): 180
Temp(Celsius): 29 | Time(Second): 181
Temp(Celsius): 29 | Time(Second): 182
Temp(Celsius): 29 | Time(Second): 183
Temp(Celsius): 29 | Time(Second): 184
Temp(Celsius): 29 | Time(Second): 185
Temp(Celsius): 29 | Time(Second): 186
Temp(Celsius): 29 | Time(Second): 187
Temp(Celsius): 29 | Time(Second): 188
Temp(Celsius): 29 | Time(Second): 189
Temp(Celsius): 29 | Time(Second): 190
Temp(Celsius): 29 | Time(Second): 191
Temp(Celsius): 29 | Time(Second): 192
Temp(Celsius): 29 | Time(Second): 193
Temp(Celsius): 29 | Time(Second): 194
Temp(Celsius): 29 | Time(Second): 195
Temp(Celsius): 30 | Time(Second): 196
Temp(Celsius): 29 | Time(Second): 197
Temp(Celsius): 30 | Time(Second): 198
Temp(Celsius): 30 | Time(Second): 199
Temp(Celsius): 30 | Time(Second): 200
Temp(Celsius): 30 | Time(Second): 201
Temp(Celsius): 30 | Time(Second): 202
Temp(Celsius): 30 | Time(Second): 203
Temp(Celsius): 30 | Time(Second): 204
Temp(Celsius): 30 | Time(Second): 205
Temp(Celsius): 30 | Time(Second): 206
Temp(Celsius): 30 | Time(Second): 207
Temp(Celsius): 30 | Time(Second): 208
Temp(Celsius): 30 | Time(Second): 209
Temp(Celsius): 30 | Time(Second): 210
Temp(Celsius): 30 | Time(Second): 211
Temp(Celsius): 30 | Time(Second): 212
Temp(Celsius): 30 | Time(Second): 213
Temp(Celsius): 30 | Time(Second): 214
Temp(Celsius): 30 | Time(Second): 215
Temp(Celsius): 30 | Time(Second): 216
Temp(Celsius): 30 | Time(Second): 217
Temp(Celsius): 30 | Time(Second): 218
Temp(Celsius): 30 | Time(Second): 219
Temp(Celsius): 30 | Time(Second): 220
Temp(Celsius): 31 | Time(Second): 221
Temp(Celsius): 30 | Time(Second): 222
Temp(Celsius): 31 | Time(Second): 223
Temp(Celsius): 31 | Time(Second): 224
Temp(Celsius): 31 | Time(Second): 225
Temp(Celsius): 31 | Time(Second): 226
Temp(Celsius): 31 | Time(Second): 227
Temp(Celsius): 31 | Time(Second): 228
Temp(Celsius): 31 | Time(Second): 229
Temp(Celsius): 31 | Time(Second): 230
Temp(Celsius): 31 | Time(Second): 231
Temp(Celsius): 31 | Time(Second): 232
Temp(Celsius): 31 | Time(Second): 233
Temp(Celsius): 31 | Time(Second): 234
Temp(Celsius): 31 | Time(Second): 235
Temp(Celsius): 31 | Time(Second): 236
Temp(Celsius): 31 | Time(Second): 237
Temp(Celsius): 31 | Time(Second): 238
Temp(Celsius): 31 | Time(Second): 239
Temp(Celsius): 31 | Time(Second): 240
Temp(Celsius): 31 | Time(Second): 241
Temp(Celsius): 31 | Time(Second): 242
Temp(Celsius): 31 | Time(Second): 243
Temp(Celsius): 31 | Time(Second): 244
Temp(Celsius): 31 | Time(Second): 245
Temp(Celsius): 31 | Time(Second): 246
Temp(Celsius): 31 | Time(Second): 247
Temp(Celsius): 31 | Time(Second): 248
Temp(Celsius): 32 | Time(Second): 249
Temp(Celsius): 32 | Time(Second): 250
Temp(Celsius): 31 | Time(Second): 251
Temp(Celsius): 32 | Time(Second): 252
Temp(Celsius): 32 | Time(Second): 253
Temp(Celsius): 32 | Time(Second): 254
Temp(Celsius): 32 | Time(Second): 255
Temp(Celsius): 32 | Time(Second): 256
Temp(Celsius): 32 | Time(Second): 257
Temp(Celsius): 32 | Time(Second): 258
Temp(Celsius): 32 | Time(Second): 259
Temp(Celsius): 32 | Time(Second): 260
Temp(Celsius): 32 | Time(Second): 261
Temp(Celsius): 32 | Time(Second): 262
Temp(Celsius): 32 | Time(Second): 263
Temp(Celsius): 32 | Time(Second): 264
Temp(Celsius): 32 | Time(Second): 265
Temp(Celsius): 32 | Time(Second): 266
Temp(Celsius): 33 | Time(Second): 267
Temp(Celsius): 32 | Time(Second): 268
Temp(Celsius): 32 | Time(Second): 269
Temp(Celsius): 32 | Time(Second): 270
Temp(Celsius): 32 | Time(Second): 271
Temp(Celsius): 33 | Time(Second): 272
Temp(Celsius): 32 | Time(Second): 273
Temp(Celsius): 32 | Time(Second): 274
Temp(Celsius): 32 | Time(Second): 275
Temp(Celsius): 32 | Time(Second): 276
Temp(Celsius): 33 | Time(Second): 277
Temp(Celsius): 33 | Time(Second): 278
Temp(Celsius): 33 | Time(Second): 279
Temp(Celsius): 33 | Time(Second): 280
Temp(Celsius): 33 | Time(Second): 281
Temp(Celsius): 33 | Time(Second): 282
Temp(Celsius): 33 | Time(Second): 283
Temp(Celsius): 33 | Time(Second): 284
Temp(Celsius): 33 | Time(Second): 285
Temp(Celsius): 33 | Time(Second): 286
Temp(Celsius): 33 | Time(Second): 287
Temp(Celsius): 33 | Time(Second): 288
Temp(Celsius): 33 | Time(Second): 289
Temp(Celsius): 33 | Time(Second): 290
Temp(Celsius): 33 | Time(Second): 291
Temp(Celsius): 33 | Time(Second): 292
Temp(Celsius): 33 | Time(Second): 293
Temp(Celsius): 33 | Time(Second): 294
Temp(Celsius): 33 | Time(Second): 295
Temp(Celsius): 33 | Time(Second): 296
Temp(Celsius): 33 | Time(Second): 297
Temp(Celsius): 33 | Time(Second): 298
Temp(Celsius): 33 | Time(Second): 299
Temp(Celsius): 33 | Time(Second): 300
Temp(Celsius): 33 | Time(Second): 301
Temp(Celsius): 33 | Time(Second): 302
Temp(Celsius): 34 | Time(Second): 303
Temp(Celsius): 34 | Time(Second): 304
Temp(Celsius): 34 | Time(Second): 305
Temp(Celsius): 34 | Time(Second): 306
Temp(Celsius): 34 | Time(Second): 307
Temp(Celsius): 34 | Time(Second): 308
Temp(Celsius): 34 | Time(Second): 309
Temp(Celsius): 34 | Time(Second): 310
Temp(Celsius): 34 | Time(Second): 311
Temp(Celsius): 34 | Time(Second): 312
Temp(Celsius): 34 | Time(Second): 313
Temp(Celsius): 34 | Time(Second): 314
Temp(Celsius): 34 | Time(Second): 315
Temp(Celsius): 34 | Time(Second): 316
Temp(Celsius): 34 | Time(Second): 317
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

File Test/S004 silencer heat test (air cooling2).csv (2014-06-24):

Tem | Time(Second): 1256
Temp(Celsius): 26 | Time(Second): 1257
Temp(Celsius): 26 | Time(Second): 0
Temp(Celsius): 26 | Time(Second): 1
Temp(Celsius): 26 | Time(Second): 2
Temp(Celsius): 26 | Time(Second): 3
Temp(Celsius): 26 | Time(Second): 4
Temp(Celsius): 26 | Time(Second): 5
Temp(Celsius): 26 | Time(Second): 6
Temp(Celsius): 26 | Time(Second): 7
Temp(Celsius): 26 | Time(Second): 8
Temp(Celsius): 26 | Time(Second): 9
Temp(Celsius): 25 | Time(Second): 10
Temp(Celsius): 26 | Time(Second): 11
Temp(Celsius): 26 | Time(Second): 12
Temp(Celsius): 26 | Time(Second): 13
Temp(Celsius): 26 | Time(Second): 14
Temp(Celsius): 26 | Time(Second): 15
Temp(Celsius): 26 | Time(Second): 16
Temp(Celsius): 26 | Time(Second): 17
Temp(Celsius): 26 | Time(Second): 18
Temp(Celsius): 26 | Time(Second): 19
Temp(Celsius): 26 | Time(Second): 20
Temp(Celsius): 26 | Time(Second): 21
Temp(Celsius): 26 | Time(Second): 22
Temp(Celsius): 26 | Time(Second): 23
Temp(Celsius): 26 | Time(Second): 24
Temp(Celsius): 25 | Time(Second): 25
Temp(Celsius): 26 | Time(Second): 26
Temp(Celsius): 26 | Time(Second): 27
Temp(Celsius): 26 | Time(Second): 28
Temp(Celsius): 26 | Time(Second): 29
Temp(Celsius): 26 | Time(Second): 30
Temp(Celsius): 26 | Time(Second): 31
Temp(Celsius): 26 | Time(Second): 32
Temp(Celsius): 26 | Time(Second): 33
Temp(Celsius): 26 | Time(Second): 34
Temp(Celsius): 26 | Time(Second): 35
Temp(Celsius): 26 | Time(Second): 36
Temp(Celsius): 26 | Time(Second): 37
Temp(Celsius): 26 | Time(Second): 38
Temp(Celsius): 26 | Time(Second): 39
Temp(Celsius): 26 | Time(Second): 40
Temp(Celsius): 26 | Time(Second): 41
Temp(Celsius): 26 | Time(Second): 42
Temp(Celsius): 26 | Time(Second): 43
Temp(Celsius): 26 | Time(Second): 44
Temp(Celsius): 26 | Time(Second): 45
Temp(Celsius): 26 | Time(Second): 46
Temp(Celsius): 26 | Time(Second): 47
Temp(Celsius): 26 | Time(Second): 48
Temp(Celsius): 26 | Time(Second): 49
Temp(Celsius): 26 | Time(Second): 50
Temp(Celsius): 26 | Time(Second): 51
Temp(Celsius): 26 | Time(Second): 52
Temp(Celsius): 26 | Time(Second): 53
Temp(Celsius): 26 | Time(Second): 54
Temp(Celsius): 26 | Time(Second): 55
Temp(Celsius): 26 | Time(Second): 56
Temp(Celsius): 26 | Time(Second): 57
Temp(Celsius): 26 | Time(Second): 58
Temp(Celsius): 26 | Time(Second): 59
Temp(Celsius): 26 | Time(Second): 60
Temp(Celsius): 26 | Time(Second): 61
Temp(Celsius): 26 | Time(Second): 62
Temp(Celsius): 26 | Time(Second): 63
Temp(Celsius): 26 | Time(Second): 64
Temp(Celsius): 26 | Time(Second): 65
Temp(Celsius): 26 | Time(Second): 66
Temp(Celsius): 26 | Time(Second): 67
Temp(Celsius): 26 | Time(Second): 68
Temp(Celsius): 26 | Time(Second): 69
Temp(Celsius): 27 | Time(Second): 70
Temp(Celsius): 27 | Time(Second): 71
Temp(Celsius): 26 | Time(Second): 72
Temp(Celsius): 27 | Time(Second): 73
Temp(Celsius): 27 | Time(Second): 74
Temp(Celsius): 27 | Time(Second): 75
Temp(Celsius): 27 | Time(Second): 76
Temp(Celsius): 27 | Time(Second): 77
Temp(Celsius): 27 | Time(Second): 78
Temp(Celsius): 27 | Time(Second): 79
Temp(Celsius): 27 | Time(Second): 80
Temp(Celsius): 27 | Time(Second): 81
Temp(Celsius): 27 | Time(Second): 82
Temp(Celsius): 27 | Time(Second): 83
Temp(Celsius): 27 | Time(Second): 84
Temp(Celsius): 27 | Time(Second): 85
Temp(Celsius): 27 | Time(Second): 86
Temp(Celsius): 27 | Time(Second): 87
Temp(Celsius): 27 | Time(Second): 88
Temp(Celsius): 27 | Time(Second): 89
Temp(Celsius): 27 | Time(Second): 90
Temp(Celsius): 27 | Time(Second): 91
Temp(Celsius): 27 | Time(Second): 92
Temp(Celsius): 27 | Time(Second): 93
Temp(Celsius): 27 | Time(Second): 94
Temp(Celsius): 28 | Time(Second): 95
Temp(Celsius): 27 | Time(Second): 96
Temp(Celsius): 27 | Time(Second): 97
Temp(Celsius): 27 | Time(Second): 98
Temp(Celsius): 28 | Time(Second): 99
Temp(Celsius): 27 | Time(Second): 100
Temp(Celsius): 28 | Time(Second): 101
Temp(Celsius): 27 | Time(Second): 102
Temp(Celsius): 28 | Time(Second): 103
Temp(Celsius): 27 | Time(Second): 104
Temp(Celsius): 28 | Time(Second): 105
Temp(Celsius): 28 | Time(Second): 106
Temp(Celsius): 28 | Time(Second): 107
Temp(Celsius): 28 | Time(Second): 108
Temp(Celsius): 28 | Time(Second): 109
Temp(Celsius): 28 | Time(Second): 110
Temp(Celsius): 28 | Time(Second): 111
Temp(Celsius): 28 | Time(Second): 112
Temp(Celsius): 28 | Time(Second): 113
Temp(Celsius): 28 | Time(Second): 114
Temp(Celsius): 28 | Time(Second): 115
Temp(Celsius): 28 | Time(Second): 116
Temp(Celsius): 28 | Time(Second): 117
Temp(Celsius): 28 | Time(Second): 118
Temp(Celsius): 28 | Time(Second): 119
Temp(Celsius): 28 | Time(Second): 120
Temp(Celsius): 28 | Time(Second): 121
Temp(Celsius): 28 | Time(Second): 122
Temp(Celsius): 28 | Time(Second): 123
Temp(Celsius): 28 | Time(Second): 124
Temp(Celsius): 28 | Time(Second): 125
Temp(Celsius): 28 | Time(Second): 126
Temp(Celsius): 28 | Time(Second): 127
Temp(Celsius): 28 | Time(Second): 128
Temp(Celsius): 28 | Time(Second): 129
Temp(Celsius): 28 | Time(Second): 130
Temp(Celsius): 28 | Time(Second): 131
Temp(Celsius): 28 | Time(Second): 132
Temp(Celsius): 28 | Time(Second): 133
Temp(Celsius): 29 | Time(Second): 134
Temp(Celsius): 28 | Time(Second): 135
Temp(Celsius): 28 | Time(Second): 136
Temp(Celsius): 28 | Time(Second): 137
Temp(Celsius): 28 | Time(Second): 138
Temp(Celsius): 29 | Time(Second): 139
Temp(Celsius): 29 | Time(Second): 140
Temp(Celsius): 28 | Time(Second): 141
Temp(Celsius): 28 | Time(Second): 142
Temp(Celsius): 29 | Time(Second): 143
Temp(Celsius): 29 | Time(Second): 144
Temp(Celsius): 28 | Time(Second): 145
Temp(Celsius): 29 | Time(Second): 146
Temp(Celsius): 28 | Time(Second): 147
Temp(Celsius): 29 | Time(Second): 148
Temp(Celsius): 28 | Time(Second): 149
Temp(Celsius): 28 | Time(Second): 150
Temp(Celsius): 29 | Time(Second): 151
Temp(Celsius): 29 | Time(Second): 152
Temp(Celsius): 29 | Time(Second): 153
Temp(Celsius): 29 | Time(Second): 154
Temp(Celsius): 29 | Time(Second): 155
Temp(Celsius): 29 | Time(Second): 156
Temp(Celsius): 29 | Time(Second): 157
Temp(Celsius): 29 | Time(Second): 158
Temp(Celsius): 29 | Time(Second): 159
Temp(Celsius): 29 | Time(Second): 160
Temp(Celsius): 29 | Time(Second): 161
Temp(Celsius): 29 | Time(Second): 162
Temp(Celsius): 29 | Time(Second): 163
Temp(Celsius): 29 | Time(Second): 164
Temp(Celsius): 29 | Time(Second): 165
Temp(Celsius): 29 | Time(Second): 166
Temp(Celsius): 29 | Time(Second): 167
Temp(Celsius): 29 | Time(Second): 168
Temp(Celsius): 29 | Time(Second): 169
Temp(Celsius): 29 | Time(Second): 170
Temp(Celsius): 29 | Time(Second): 171
Temp(Celsius): 29 | Time(Second): 172
Temp(Celsius): 29 | Time(Second): 173
Temp(Celsius): 29 | Time(Second): 174
Temp(Celsius): 29 | Time(Second): 175
Temp(Celsius): 29 | Time(Second): 176
Temp(Celsius): 29 | Time(Second): 177
Temp(Celsius): 29 | Time(Second): 178
Temp(Celsius): 29 | Time(Second): 179
Temp(Celsius): 29 | Time(Second): 180
Temp(Celsius): 29 | Time(Second): 181
Temp(Celsius): 29 | Time(Second): 182
Temp(Celsius): 29 | Time(Second): 183
Temp(Celsius): 29 | Time(Second): 184
Temp(Celsius): 29 | Time(Second): 185
Temp(Celsius): 29 | Time(Second): 186
Temp(Celsius): 29 | Time(Second): 187
Temp(Celsius): 29 | Time(Second): 188
Temp(Celsius): 29 | Time(Second): 189
Temp(Celsius): 29 | Time(Second): 190
Temp(Celsius): 29 | Time(Second): 191
Temp(Celsius): 29 | Time(Second): 192
Temp(Celsius): 29 | Time(Second): 193
Temp(Celsius): 29 | Time(Second): 194
Temp(Celsius): 29 | Time(Second): 195
Temp(Celsius): 29 | Time(Second): 196
Temp(Celsius): 29 | Time(Second): 197
Temp(Celsius): 29 | Time(Second): 198
Temp(Celsius): 29 | Time(Second): 199
Temp(Celsius): 29 | Time(Second): 200
Temp(Celsius): 29 | Time(Second): 201
Temp(Celsius): 29 | Time(Second): 202
Temp(Celsius): 29 | Time(Second): 203
Temp(Celsius): 29 | Time(Second): 204
Temp(Celsius): 29 | Time(Second): 205
Temp(Celsius): 29 | Time(Second): 206
Temp(Celsius): 29 | Time(Second): 207
Temp(Celsius): 29 | Time(Second): 208
Temp(Celsius): 29 | Time(Second): 209
Temp(Celsius): 29 | Time(Second): 210
Temp(Celsius): 29 | Time(Second): 211
Temp(Celsius): 29 | Time(Second): 212
Temp(Celsius): 29 | Time(Second): 213
Temp(Celsius): 29 | Time(Second): 214
Temp(Celsius): 29 | Time(Second): 215
Temp(Celsius): 29 | Time(Second): 216
Temp(Celsius): 29 | Time(Second): 217
Temp(Celsius): 29 | Time(Second): 218
Temp(Celsius): 29 | Time(Second): 219
Temp(Celsius): 29 | Time(Second): 220
Temp(Celsius): 29 | Time(Second): 221
Temp(Celsius): 29 | Time(Second): 222
Temp(Celsius): 29 | Time(Second): 223
Temp(Celsius): 29 | Time(Second): 224
Temp(Celsius): 29 | Time(Second): 225
Temp(Celsius): 30 | Time(Second): 226
Temp(Celsius): 30 | Time(Second): 227
Temp(Celsius): 29 | Time(Second): 228
Temp(Celsius): 29 | Time(Second): 229
Temp(Celsius): 30 | Time(Second): 230
Temp(Celsius): 29 | Time(Second): 231
Temp(Celsius): 30 | Time(Second): 232
Temp(Celsius): 29 | Time(Second): 233
Temp(Celsius): 29 | Time(Second): 234
Temp(Celsius): 29 | Time(Second): 235
Temp(Celsius): 29 | Time(Second): 236
Temp(Celsius): 29 | Time(Second): 237
Temp(Celsius): 29 | Time(Second): 238
Temp(Celsius): 29 | Time(Second): 239
Temp(Celsius): 30 | Time(Second): 240
Temp(Celsius): 29 | Time(Second): 241
Temp(Celsius): 30 | Time(Second): 242
Temp(Celsius): 30 | Time(Second): 243
Temp(Celsius): 29 | Time(Second): 244
Temp(Celsius): 29 | Time(Second): 245
Temp(Celsius): 29 | Time(Second): 246
Temp(Celsius): 29 | Time(Second): 247
Temp(Celsius): 30 | Time(Second): 248
Temp(Celsius): 30 | Time(Second): 249
Temp(Celsius): 30 | Time(Second): 250
Temp(Celsius): 30 | Time(Second): 251
Temp(Celsius): 30 | Time(Second): 252
Temp(Celsius): 30 | Time(Second): 253
Temp(Celsius): 29 | Time(Second): 254
Temp(Celsius): 29 | Time(Second): 255
Temp(Celsius): 30 | Time(Second): 256
Temp(Celsius): 30 | Time(Second): 257
Temp(Celsius): 30 | Time(Second): 258
Temp(Celsius): 29 | Time(Second): 259
Temp(Celsius): 30 | Time(Second): 260
Temp(Celsius): 29 | Time(Second): 261
Temp(Celsius): 30 | Time(Second): 262
Temp(Celsius): 30 | Time(Second): 263
Temp(Celsius): 30 | Time(Second): 264
Temp(Celsius): 30 | Time(Second): 265
Temp(Celsius): 30 | Time(Second): 266
Temp(Celsius): 29 | Time(Second): 267
Temp(Celsius): 29 | Time(Second): 268
Temp(Celsius): 30 | Time(Second): 269
Temp(Celsius): 30 | Time(Second): 270
Temp(Celsius): 30 | Time(Second): 271
Temp(Celsius): 30 | Time(Second): 272
Temp(Celsius): 30 | Time(Second): 273
Temp(Celsius): 30 | Time(Second): 274
Temp(Celsius): 29 | Time(Second): 275
Temp(Celsius): 29 | Time(Second): 276
Temp(Celsius): 29 | Time(Second): 277
Temp(Celsius): 30 | Time(Second): 278
Temp(Celsius): 30 | Time(Second): 279
Temp(Celsius): 30 | Time(Second): 280
Temp(Celsius): 30 | Time(Second): 281
Temp(Celsius): 30 | Time(Second): 282
Temp(Celsius): 29 | Time(Second): 283
Temp(Celsius): 30 | Time(Second): 284
Temp(Celsius): 29 | Time(Second): 285
Temp(Celsius): 30 | Time(Second): 286
Temp(Celsius): 30 | Time(Second): 287
Temp(Celsius): 30 | Time(Second): 288
Temp(Celsius): 29 | Time(Second): 289
Temp(Celsius): 30 | Time(Second): 290
Temp(Celsius): 30 | Time(Second): 291
Temp(Celsius): 30 | Time(Second): 292
Temp(Celsius): 30 | Time(Second): 293
Temp(Celsius): 30 | Time(Second): 294
Temp(Celsius): 30 | Time(Second): 295
Temp(Celsius): 30 | Time(Second): 296
Temp(Celsius): 30 | Time(Second): 297
Temp(Celsius): 29 | Time(Second): 298
Temp(Celsius): 29 | Time(Second): 299
Temp(Celsius): 30 | Time(Second): 300
Temp(Celsius): 29 | Time(Second): 301
Temp(Celsius): 30 | Time(Second): 302
Temp(Celsius): 30 | Time(Second): 303
Temp(Celsius): 29 | Time(Second): 304
Temp(Celsius): 30 | Time(Second): 305
Temp(Celsius): 30 | Time(Second): 306
Temp(Celsius): 30 | Time(Second): 307
Temp(Celsius): 29 | Time(Second): 308
Temp(Celsius): 30 | Time(Second): 309
Temp(Celsius): 30 | Time(Second): 310
Temp(Celsius): 30 | Time(Second): 311
Temp(Celsius): 30 | Time(Second): 312
Temp(Celsius): 30 | Time(Second): 313
Temp(Celsius): 30 | Time(Second): 314
Temp(Celsius): 29 | Time(Second): 315
Temp(Celsius): 30 | Time(Second): 316
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

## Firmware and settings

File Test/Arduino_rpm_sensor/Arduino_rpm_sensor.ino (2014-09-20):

int sec = 0;//開始からのミリ秒数
unsigned char tv[1000];//1秒間の計測値
int count=0;

void setup() {
  Serial.begin(9600) ;      // パソコン(ArduinoIDE)とシリアル通信の準備を行う
}

void loop() {
  int ans;
  ans = analogRead(0) ;              // アナログ０番ピンからセンサー値を読込む
  tv[count]  = map(ans,0,1023,0,255) ;     // センサー値を8bitに変換する
  
  if(count==999){ // countが999なら1秒経過したので計測結果をrpmで表示
    int hit = 0;
    int rpm = 0;
    
    // 1秒間の回転数を平均して算出する
    // 1秒間に何回刃先を検出したかをカウントしてrpmを算出
    // 2枚刃のエンドミルを前提として計算
    
    for (int i=1;i<1000;i++) {
      if ((tv[i] - tv[i-1])>2) {//電圧アップしたら刃先検出
        hit++;
      }
    }
    
    rpm = hit * 30;
    
    Serial.print("RPM: ");
    Serial.print(rpm);             // 値をパソコン(ＩＤＥ)に送る
    Serial.print(", Time(second): ");
    Serial.println(sec);
    
    sec++;
    count = 0; //カウントを初期化
  }else{
    count ++;
  }
  delayMicroseconds(997) ;                      // 1ミリ秒毎に繰り返す
}

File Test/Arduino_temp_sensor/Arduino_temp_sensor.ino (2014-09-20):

int sec = 0;

void setup() {
  Serial.begin(9600) ;      // パソコン(ArduinoIDE)とシリアル通信の準備を行う
}

void loop() {
  int ans , temp , tv;
  ans = analogRead(0) ;              // アナログ０番ピンからセンサー値を読込む
  tv  = map(ans,0,1023,0,5000) ;     // センサー値を電圧に変換する
  temp = map(tv,300,1600,-30,100);  // 電圧から温度に変換する
  Serial.print("Temp(Celsius): ");
  Serial.print(temp);             // 値をパソコン(ＩＤＥ)に送る
  Serial.print(", Time(Second): ");
  Serial.println(sec);
  sec = sec + 1;
  delay(1000) ;                      // １秒毎に繰り返す
}

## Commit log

2014-05-17 Spindle motor housing re-design for EMC/noize
2014-05-20 Change Z axis shaft dia 8 to 10mm with calc.
2014-05-20 Spindle support for 3d print added
2014-06-08 cariculate force effects of spindle/Z axis
2014-06-10 Collecting info on motor silencer & EM noise
2014-06-12 square design spindle added
2014-06-14 S001 dc housing stl added & print
    [S001 dc housing.stl]
2014-06-15 S001 housing with inner silencer design stl
    [S001 dc housing.stl]
2014-06-15 dc housing tall adjusted
    [S001 dc housing.stl]
2014-06-15 silencer stl added
    [S004 silencer.stl]
2014-06-15 housing, silencer and spindle re-design
2014-06-18 CAD, split silencer to S004 and S005 for easier assembly
    [S004 silencer.stl, S005 silencer cover.stl]
2014-06-24 Test results of silencer heat effect. It show cooling fan required to reduce heat.
    [S004 silencer heat test (air cooling).csv, S004 silencer heat test (air cooling2).csv, S004 silencer heat test (air cooling2_1).csv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]
2014-06-24 Spindle re-design finished
    [S001 dc housing.stl, S002 spindle.stl, S005 silencer cover.stl]
2014-06-24 Re-design of z carriage. Increase of rigidness and x axis stepper configuration are changed.
    [X Motor Housing.3dm]
2014-06-24 stl added
    [X001 motor housing.stl]
2014-06-29 x motor housing printed version
    [X Motor Housing.3dm, X001 motor housing.stl]
2014-06-29 smooth idler print & z carriage print time checked
    [U001 smooth idler.stl, Z001 z carriage.stl]
2014-07-03 spacer printed
    [U001-2 spacer.stl]
2014-07-05 Z Carriage re-design
    [Cable Carriror.3dm]
2014-07-07 Z cover, carriage, dust skirt and z motor mount CAD almost fixed
    [Z Carriage Cover.3dm, Z Carriage.3dm, Z Motor Mount.3dm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]
2014-07-23 1st draft of 2.0 design. X gantry re-designed to improve rigidness and motor mounts configuration changed like shapeoko. Y frames are also changed along with motor mounts.
    [X007 right bracket.stl, Y001 y motor mount.stl, Y001-1 belt lock.3dm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]
2014-07-26 printing gantry brakets
    [X003 right bracket.3dm, X003 right bracket.stl, X005 left bracket.3dm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]
2014-09-08 Mule2.0 Release candidate grade design
    [U001-3 spacer.stl, X005-2 adjuster handle.stl, X005-3 belt lock.stl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]
2014-09-20 RPM/Temp sensor with arduino
    [SensorMount.stl]
2014-09-20 Silencer improvement: motor change, housing design change
    [S001 dc housing 2.2.stl, S005 silencer cover 2.2.stl]
2014-10-12 Spindle re-design for noise reduction
    [S001 dc housing 2.2.stl, S002 spindle 2.2.stl]
2014-11-09 Brushup. 1.Unnecessory stl & md removed. 2. Lisence & walkthrough added for user convinience. 3. dc housing stl is replaced with correct data. 4. silencer study updated
    [S001 dc housing 2.2.stl, S002 spindle.stl, S004 silencer.stl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]
